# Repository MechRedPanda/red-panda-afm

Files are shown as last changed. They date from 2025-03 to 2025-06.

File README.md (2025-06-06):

# red-panda-afm
Build your own AFM for cheap!
## Background
This project aims to create a low-cost Atomic Force Microscope (AFM) using a 3D printer. The goal is to make AFM technology accessible and affordable for hobbyists and researchers.

## Features
- **Low Cost**: Utilizes 3D printing to reduce manufacturing costs.
- **DIY Friendly**: Designed for easy assembly and use.

## Requirements
- 3D Printer
- PCB and soldering
- OPU
- AFM probe

## Getting Started
Ready to build your own AFM? Check out our comprehensive [Building Instructions](BUILD_GUIDE.md) for step-by-step assembly guidance.

## License
This project is licensed under the MIT License.

## Contact
For any questions or support, please contact [your-email@example.com].

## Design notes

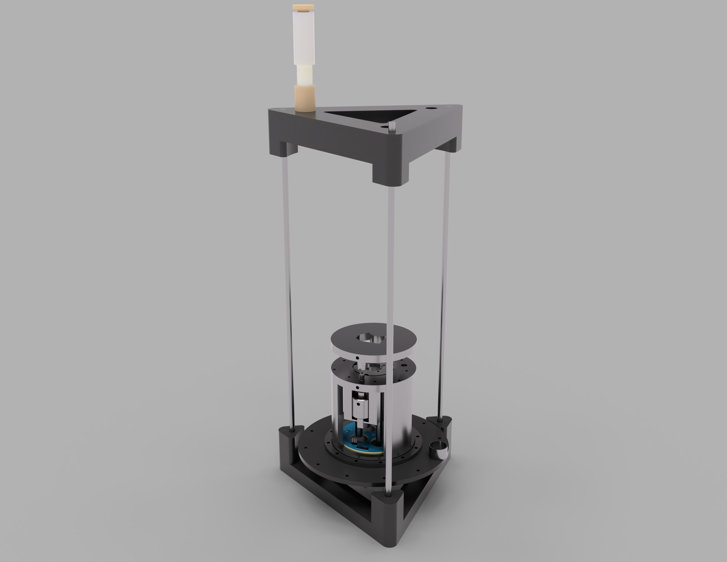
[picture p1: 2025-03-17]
cad/afm/ScanStage_2025-Mar-13_04-19-15AM-000_CustomizedView51960820746.png

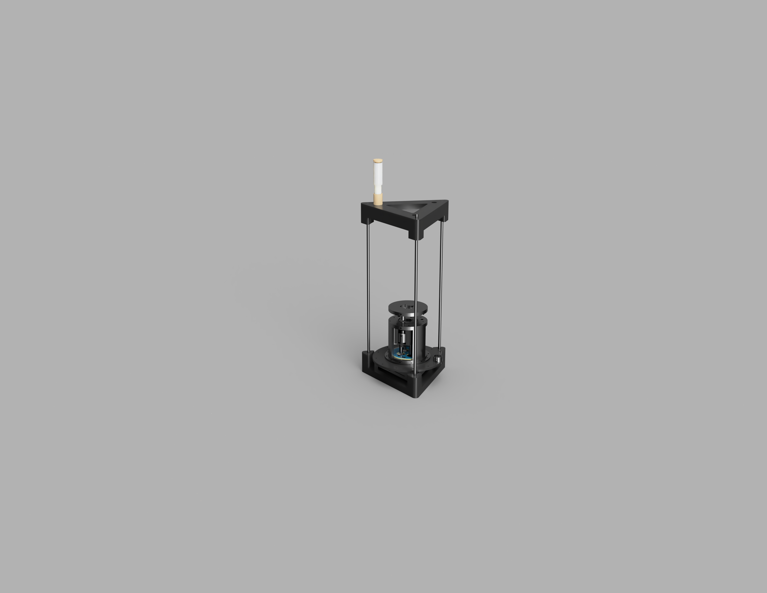
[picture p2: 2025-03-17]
cad/afm/ScanStage_2025-Mar-13_04-14-37AM-000_CustomizedView17416114158.png

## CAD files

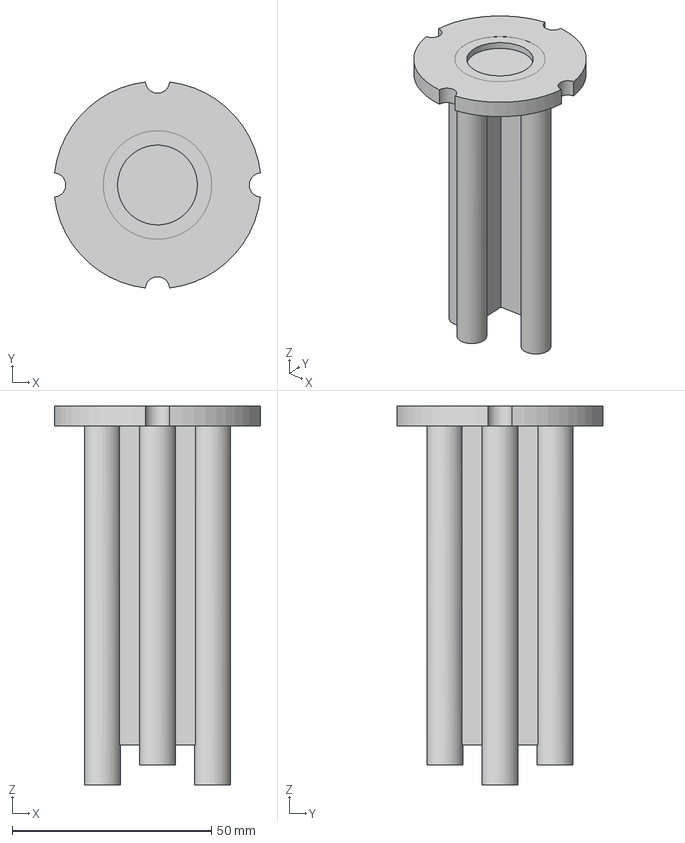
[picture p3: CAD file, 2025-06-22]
cad/afm/LongRagneScanner.step
51.7 x 51.7 x 95.0 mm

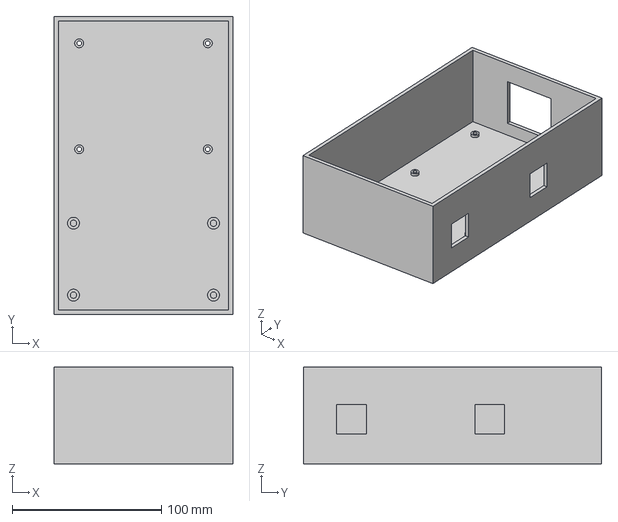
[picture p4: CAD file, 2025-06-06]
cad/afm/PCB_Box/PCB_Box_Lower.step
120.0 x 200.0 x 65.0 mm

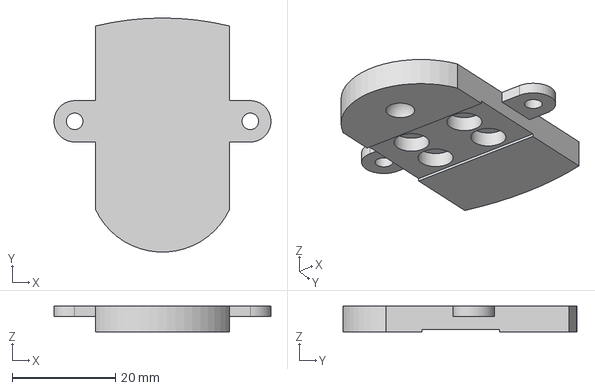
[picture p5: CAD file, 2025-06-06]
cad/afm/PCB_Box/ProbeHolderAdaptor.step
42.0 x 45.3 x 5.00 mm

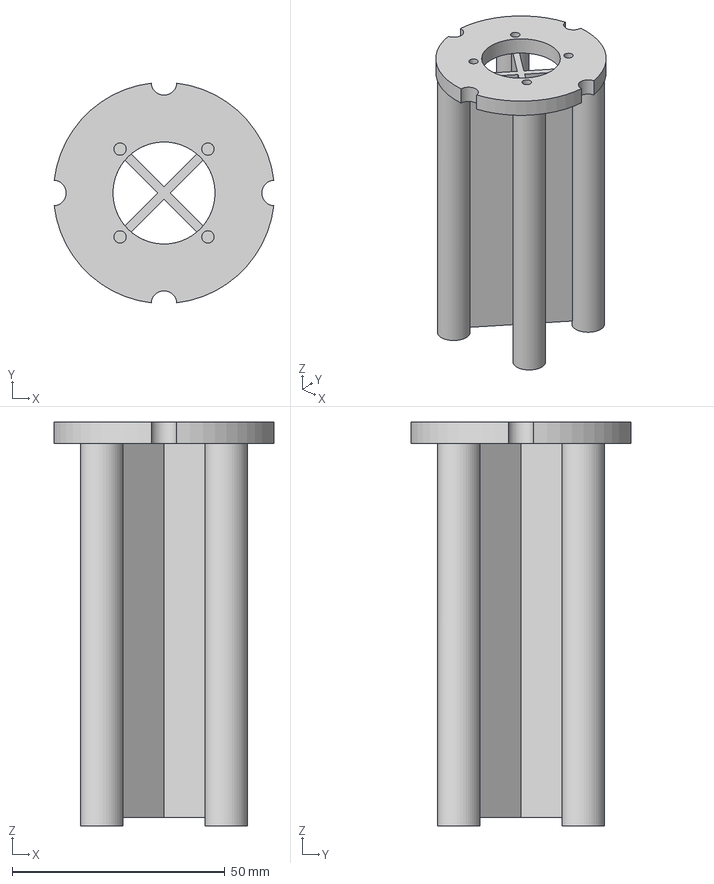
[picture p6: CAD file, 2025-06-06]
cad/afm/Scanner.step
51.7 x 51.7 x 95.0 mm

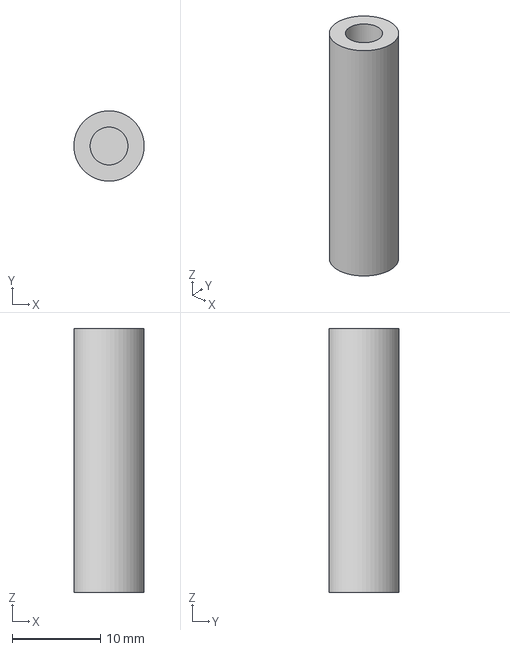
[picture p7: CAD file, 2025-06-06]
cad/afm/PCB_Box/Spacer.step
7.99 x 8.00 x 30.0 mm

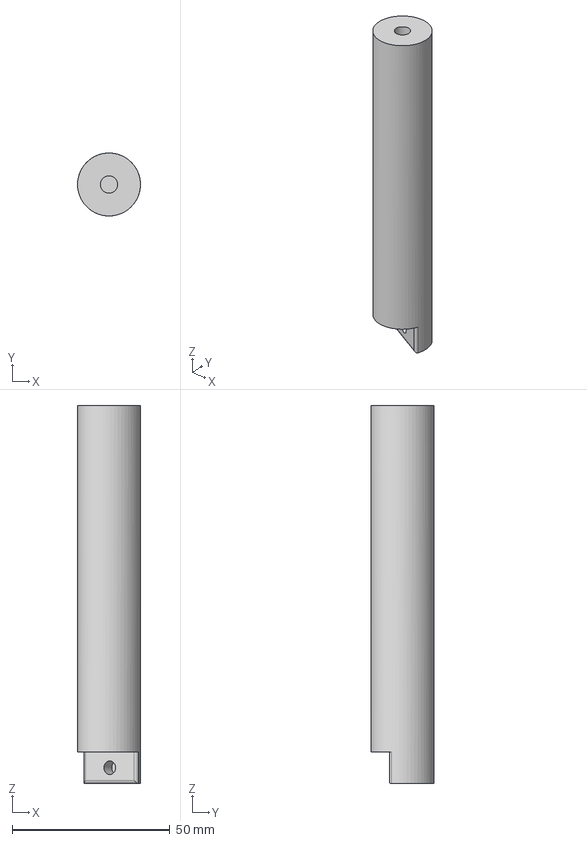
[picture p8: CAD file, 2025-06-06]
cad/afm/PlatformPillar.step
20.0 x 20.0 x 120.0 mm

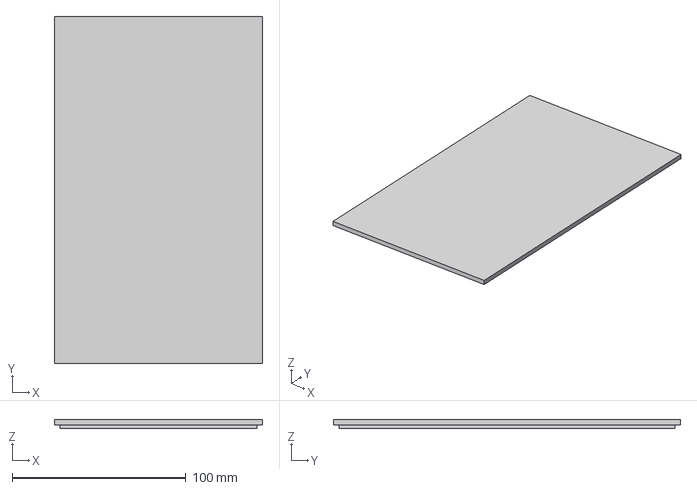
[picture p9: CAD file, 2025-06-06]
cad/afm/PCB_Box/PCB_Box_Cap.step
120.0 x 200.0 x 5.00 mm

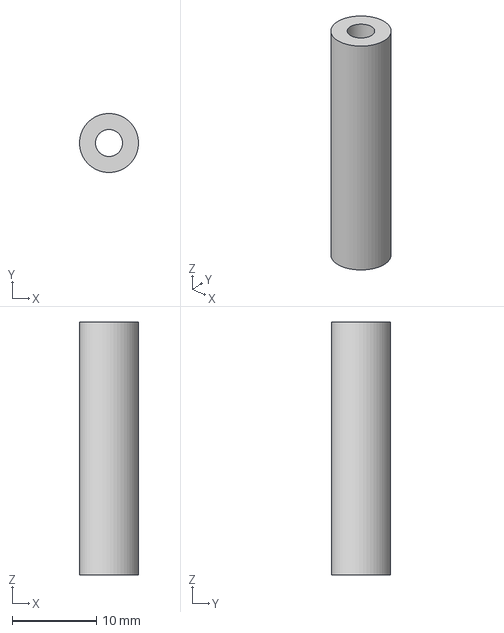
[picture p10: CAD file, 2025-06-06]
cad/afm/Spacer.step
6.99 x 7.00 x 30.0 mm

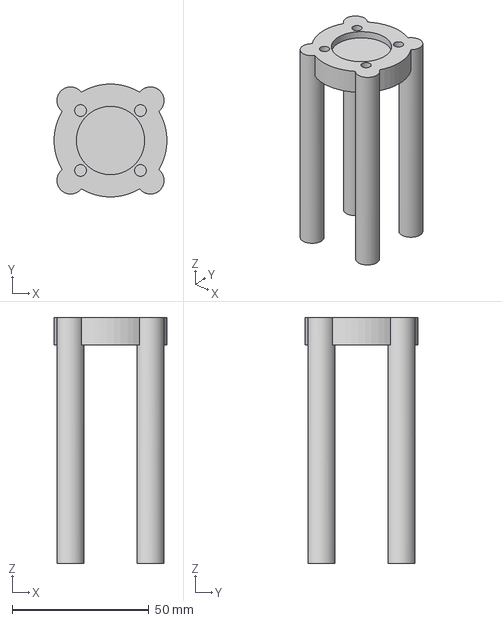
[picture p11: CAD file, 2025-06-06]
cad/afm/Sannerhead.step
41.2 x 41.2 x 90.0 mm

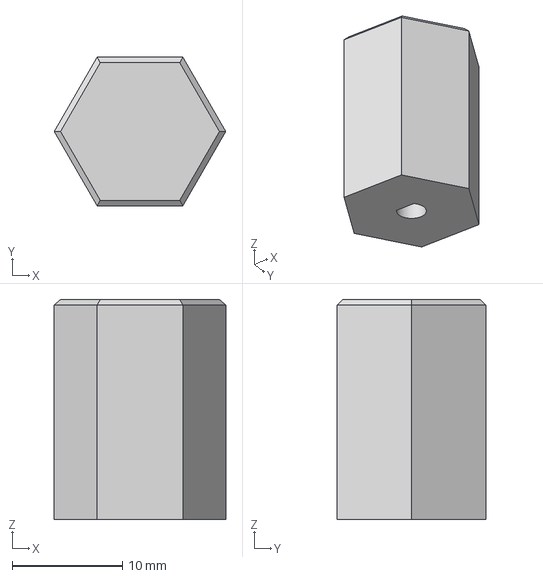
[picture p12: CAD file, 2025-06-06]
cad/afm/Shaft.step
15.6 x 13.5 x 20.0 mm

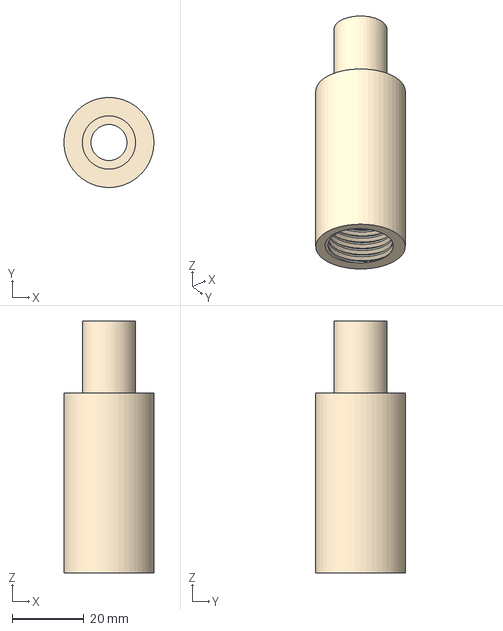
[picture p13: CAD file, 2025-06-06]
cad/afm/SpringHanger.step
25.0 x 25.0 x 70.0 mm

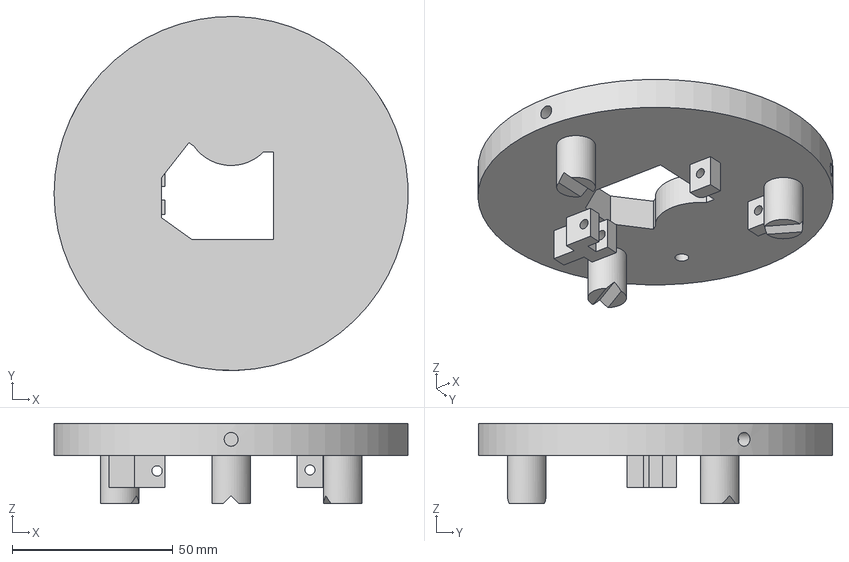
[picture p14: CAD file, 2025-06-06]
cad/afm/OPU_Plate.step
109.9 x 110.0 x 25.0 mm

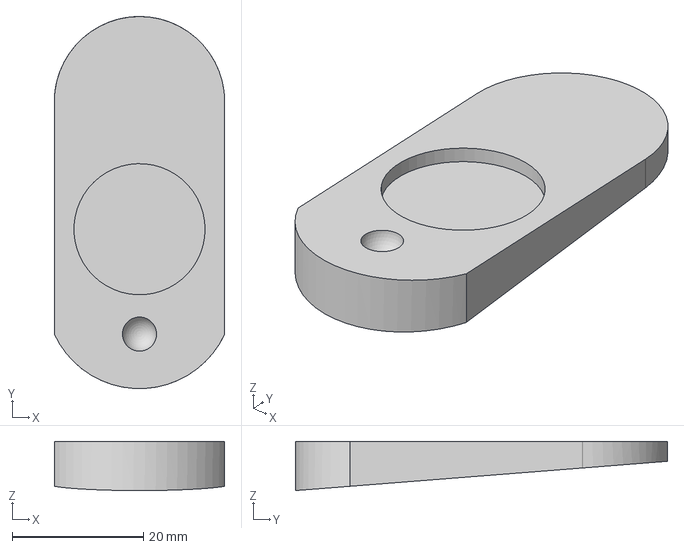
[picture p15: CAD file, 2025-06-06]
cad/afm/ProbeHolder.step
26.0 x 56.7 x 7.50 mm

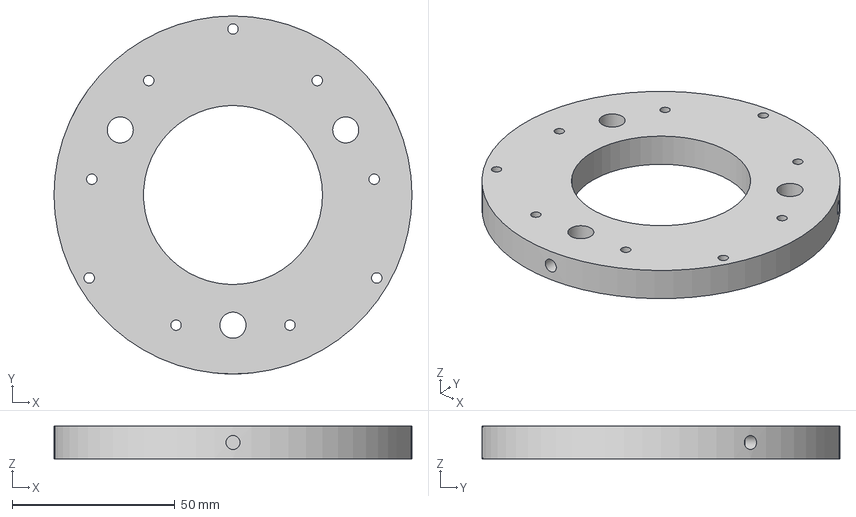
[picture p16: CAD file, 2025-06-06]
cad/afm/UpperFrame.step
110.0 x 110.0 x 10.0 mm

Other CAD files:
cad/afm/StepMotorUpperFrame.step
cad/afm/StepMotorUpperFrame2.step
cad/afm/KnobAdaptor.step
cad/afm/ProbeHolderAdaptor.step
cad/afm/AFM_Adaptor.step
cad/afm/LowerFrame.step
cad/afm/OPU_Tuning_Stand.step
cad/afm/PiezoAdaptor.step
cad/afm/Sannerhead.3mf
cad/afm/SpringExtension.step
cad/afm/StepMotorUpperFrame1.step

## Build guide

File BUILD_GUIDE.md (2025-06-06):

# DIY AFM Building Instructions

## Overview
This guide will walk you through building your own low-cost Atomic Force Microscope (AFM) using 3D printed components and readily available electronic parts.

## Required Materials

### 3D Printed Components
- Main frame structure
- Sample stage
- Cantilever mount
- Optical head assembly housing
- Z-axis adjustment mechanism

### Electronic Components
- **OPU (Optical Pick-Up Unit)**: DVD/Blu-ray laser assembly
- **AFM Probe/Cantilever**: Silicon nitride or silicon cantilever
- **Photodiode**: For detecting cantilever deflection
- **Piezoelectric actuators**: For fine positioning (X, Y, Z axes)
- **Arduino/microcontroller**: For control and data acquisition
- **Operational amplifiers**: For signal conditioning
- **Resistors and capacitors**: Various values for circuit construction

### Tools Required
- Soldering iron and solder
- Multimeter
- Small screwdrivers (Phillips and flathead)
- Wire strippers
- Hot glue gun (optional)
- Computer with USB port

## Assembly Steps

### Step 1: 3D Print Components
1. Download and print all STL files using PLA or PETG filament
2. Use 0.2mm layer height for best results
3. Support material may be required for some components
4. Post-process printed parts by removing supports and light sanding if needed

### Step 2: Prepare Electronics
1. **OPU Preparation**:
   - Carefully disassemble DVD/Blu-ray drive to extract OPU
   - Identify laser diode pins and photodiode connections
   - Test laser functionality with appropriate current limiting

2. **Control Circuit Assembly**:
   - Solder operational amplifier circuit for photodiode signal conditioning
   - Connect piezoelectric actuators to driver circuits
   - Wire Arduino/microcontroller to control interfaces

### Step 3: Mechanical Assembly
1. **Frame Assembly**:
   - Assemble main frame components
   - Install sample stage with smooth movement
   - Mount Z-axis adjustment mechanism

2. **Optical System Setup**:
   - Install OPU in optical head housing
   - Align laser beam path
   - Position photodiode for optimal signal detection

3. **Cantilever Mount**:
   - Install AFM probe/cantilever in mount
   - Ensure proper alignment with laser beam
   - Test mechanical stability

### Step 4: Electronics Integration
1. Connect all electronic components according to circuit diagram
2. Install control software on computer
3. Test all actuators and sensors
4. Calibrate photodiode response

### Step 5: Initial Testing
1. **System Check**:
   - Verify all connections
   - Test laser safety (never look directly into beam)
   - Check piezo actuator response

2. **Basic Functionality Test**:
   - Load test sample (e.g., calibration grating)
   - Attempt basic scanning operation
   - Verify data acquisition

## Safety Considerations

⚠️ **IMPORTANT SAFETY NOTES**:
- **Laser Safety**: Never look directly into the laser beam
- **Electrical Safety**: Ensure proper grounding and current limiting
- **Mechanical Safety**: Be careful with sharp AFM probes
- **Work in well-lit area** with proper ventilation when soldering

## Calibration

### Initial Calibration Steps
1. **Optical Alignment**:
   - Align laser spot on cantilever
   - Center photodiode signal
   - Optimize signal-to-noise ratio

2. **Mechanical Calibration**:
   - Calibrate piezo actuator sensitivity
   - Set appropriate feedback parameters
   - Test approach/retract functionality

## Troubleshooting

### Common Issues
- **No laser signal**: Check laser diode connections and current limiting
- **Poor image quality**: Verify cantilever alignment and cleanliness
- **Instability**: Check for vibrations and improve isolation
- **Electrical noise**: Improve shielding and grounding

### Performance Optimization
- Use vibration isolation table if available
- Shield electronics from electromagnetic interference
- Keep cables short and well-routed
- Regular maintenance of moving parts

## Software Setup
1. Install required drivers for microcontroller
2. Download AFM control software
3. Configure communication parameters
4. Test data acquisition and display

## Expected Performance
- **Lateral resolution**: ~100 nm (depending on probe quality)
- **Vertical resolution**: ~1 nm
- **Scan range**: Limited by piezo actuator range
- **Scan speed**: Variable, typically 0.1-10 Hz

## Next Steps
- Start with simple test samples (calibration gratings)
- Gradually move to more complex samples
- Consider upgrading components for better performance
- Join AFM community forums for tips and troubleshooting

## Support
For additional help and community support, refer to:
- Project repository issues section
- AFM hobbyist forums
- Local maker spaces with electronics expertise

---
**Note**: This is a complex project requiring patience and attention to detail. Take your time with each step and don't hesitate to ask for help when needed.

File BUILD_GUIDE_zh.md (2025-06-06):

# DIY AFM 制作说明

## 概述
本指南将指导您使用3D打印组件和现成的电子元件制作自己的低成本原子力显微镜（AFM）。

## 所需材料

### 3D打印组件
- 主框架结构
- 样品台
- 悬臂梁支架
- 光学头组件外壳
- Z轴调节机构

### 电子元件
- **OPU（光学拾取器）**: DVD/蓝光激光组件
- **AFM探针/悬臂梁**: 氮化硅或硅悬臂梁
- **光电二极管**: 用于检测悬臂梁偏转
- **压电驱动器**: 用于精密定位（X、Y、Z轴）
- **Arduino/微控制器**: 用于控制和数据采集
- **运算放大器**: 用于信号调理
- **电阻和电容**: 各种规格用于电路构建

### 所需工具
- 电烙铁和焊锡
- 万用表
- 小型螺丝刀（十字和一字）
- 剥线钳
- 热熔胶枪（可选）
- 带USB接口的计算机

## 组装步骤

### 步骤1: 3D打印组件
1. 下载并使用PLA或PETG耗材打印所有STL文件
2. 使用0.2mm层高以获得最佳效果
3. 某些组件可能需要支撑材料
4. 通过移除支撑和轻微打磨对打印件进行后处理

### 步骤2: 准备电子元件
1. **OPU准备**:
   - 小心拆解DVD/蓝光驱动器以提取OPU
   - 识别激光二极管引脚和光电二极管连接
   - 使用适当的限流测试激光功能

2. **控制电路组装**:
   - 焊接用于光电二极管信号调理的运算放大器电路
   - 连接压电驱动器到驱动电路
   - 将Arduino/微控制器连接到控制接口

### 步骤3: 机械组装
1. **框架组装**:
   - 组装主框架组件
   - 安装具有平滑运动的样品台
   - 安装Z轴调节机构

2. **光学系统设置**:
   - 将OPU安装在光学头外壳中
   - 对准激光束路径
   - 定位光电二极管以获得最佳信号检测

3. **悬臂梁支架**:
   - 在支架中安装AFM探针/悬臂梁
   - 确保与激光束的正确对准
   - 测试机械稳定性

### 步骤4: 电子集成
1. 根据电路图连接所有电子组件
2. 在计算机上安装控制软件
3. 测试所有驱动器和传感器
4. 校准光电二极管响应

### 步骤5: 初始测试
1. **系统检查**:
   - 验证所有连接
   - 测试激光安全（绝不直视光束）
   - 检查压电驱动器响应

2. **基本功能测试**:
   - 加载测试样品（如校准光栅）
   - 尝试基本扫描操作
   - 验证数据采集

## 安全注意事项

⚠️ **重要安全注意事项**:
- **激光安全**: 绝不直视激光束
- **电气安全**: 确保正确接地和限流
- **机械安全**: 小心尖锐的AFM探针
- **在照明良好的区域工作**，焊接时保持良好通风

## 校准

### 初始校准步骤
1. **光学对准**:
   - 将激光点对准悬臂梁
   - 居中光电二极管信号
   - 优化信噪比

2. **机械校准**:
   - 校准压电驱动器灵敏度
   - 设置适当的反馈参数
   - 测试接近/撤回功能

## 故障排除

### 常见问题
- **无激光信号**: 检查激光二极管连接和限流
- **图像质量差**: 验证悬臂梁对准和清洁度
- **不稳定**: 检查振动并改善隔离
- **电气噪声**: 改善屏蔽和接地

### 性能优化
- 如有条件，使用防振台
- 屏蔽电子元件免受电磁干扰
- 保持电缆短且布线良好
- 定期维护运动部件

## 软件设置
1. 为微控制器安装所需驱动程序
2. 下载AFM控制软件
3. 配置通信参数
4. 测试数据采集和显示

## 预期性能
- **横向分辨率**: ~100 nm（取决于探针质量）
- **纵向分辨率**: ~1 nm
- **扫描范围**: 受压电驱动器范围限制
- **扫描速度**: 可变，通常0.1-10 Hz

## 下一步
- 从简单的测试样品开始（校准光栅）
- 逐渐转向更复杂的样品
- 考虑升级组件以获得更好的性能
- 加入AFM社区论坛获取技巧和故障排除

## 支持
有关额外帮助和社区支持，请参考：
- 项目仓库问题部分
- AFM爱好者论坛
- 具有电子专业知识的本地创客空间

---
**注意**: 这是一个复杂的项目，需要耐心和对细节的关注。在每个步骤上花时间，需要帮助时不要犹豫。

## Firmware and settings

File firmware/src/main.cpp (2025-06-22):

#include "AD5761.hpp"
#include "ads8681.hpp"
#include <ArduinoJson.h>
#include <atomic>
#include <mutex>
#include "esp_task_wdt.h"
#include <cstring> // Needed for memcpy
#include <WiFi.h>  // Add WiFi library

// For thread synchronization
#include "freertos/FreeRTOS.h"
#include "freertos/semphr.h"
#include "freertos/portmacro.h"

// ============================================================================
// Configuration
// ============================================================================
#define DEBUG_ENABLED 0 // Set to 0 to disable all debug output

// Debug output macros - these will compile to nothing when debugging is disabled
#if DEBUG_ENABLED
#define DEBUG_PRINT(x) Serial.print(x)
#define DEBUG_PRINTLN(x) Serial.println(x)
#define DEBUG_PRINTF(format, ...) Serial.printf(format, __VA_ARGS__)
#else
#define DEBUG_PRINT(x)
#define DEBUG_PRINTLN(x)
#define DEBUG_PRINTF(format, ...)
#endif

// Forward declarations
void sendScanDataBuffer();

// ============================================================================
// PID Controller Class
// ============================================================================

class PIDController
{
public:
    PIDController(float kp = 1.0f, float ki = 0.0f, float kd = 0.0f,
                  float integralMin = -50000.0f, float integralMax = 50000.0f,
                  float slewRate = 100000.0f)
        : kp_(kp), ki_(ki), kd_(kd), integral_min_(integralMin),
          integral_max_(integralMax), slew_rate_(slewRate)
    {
        reset();
    }

    void setTunings(float kp, float ki, float kd)
    {
        kp_ = kp;
        ki_ = ki;
        kd_ = kd;
    }

    void setOutputLimits(float min, float max)
    {
        output_min_ = min;
        output_max_ = max;
    }

    void setIntegralLimits(float min, float max)
    {
        integral_min_ = min;
        integral_max_ = max;
    }

    void setSlewRate(float rate)
    {
        slew_rate_ = rate;
    }

    void reset()
    {
        integral_ = 0;
        last_error_ = 0;
        last_feedback_ = 0;
        last_output_ = 0;
        last_time_ = 0;  // Initialize to 0 to trigger first run protection
        filtered_d_term_ = 0;
    }

    float compute(float setpoint, float feedback)
    {
        uint64_t now = esp_timer_get_time();
        uint32_t dt = now - last_time_;
        
        // First run protection
        if (last_time_ == 0) {
            last_time_ = now;
            last_feedback_ = feedback;
            // Calculate initial output using proportional term only
            float error = setpoint - feedback;
            if (invert_)
                error = -error;
            last_output_ = kp_ * error + bias_;  // Initialize with proportional term plus bias
            return last_output_;
        }

        // Clamp minimum dt to 10us to prevent erratic integral updates
        if (dt < 100) dt = 100;

        float error = setpoint - feedback;
        if (invert_)
            error = -error;

        // Proportional term
        float p_term = kp_ * error;

        // Integral term with simple anti-windup (just clamping)
        integral_ += ki_ * error * dt / 1000000.0f;  // Convert microseconds to seconds
        integral_ = constrain(integral_, integral_min_, integral_max_);

        // Derivative term calculation (skip if Kd = 0)
        float d_term = 0.0f;
        if (kd_ != 0.0f) {
            float d_term_raw = -kd_ * (feedback - last_feedback_) / (dt / 1000000.0f);
            filtered_d_term_ = alpha_ * filtered_d_term_ + (1.0f - alpha_) * d_term_raw;
            d_term = filtered_d_term_;
        }

        // Calculate output with bias
        float pid_output = p_term + integral_ + d_term;
        float desired_output = pid_output + bias_;

        // Slew rate limiting
        float max_change = slew_rate_ * dt / 1000000.0f;
        float delta = desired_output - last_output_;
        if (abs(delta) > max_change)
        {
            delta = (delta > 0) ? max_change : -max_change;
        }
        float output = last_output_ + delta;

        // Output limiting
        output = constrain(output, output_min_, output_max_);

        // Update state
        last_error_ = error;
        last_feedback_ = feedback;
        last_output_ = output;
        last_time_ = now;

        return output;
    }

    void setInvert(bool invert) { invert_ = invert; }
    void setBias(float bias) { bias_ = bias; }
    void setAlpha(float alpha) { alpha_ = constrain(alpha, 0.0f, 1.0f); }

    // Getter methods
    float getKp() const { return kp_; }
    float getKi() const { return ki_; }
    float getKd() const { return kd_; }
    float getIntegral() const { return integral_; }
    float getBias() const { return bias_; }
    float getCurrentOutput() const { return last_output_; }
    bool getInvert() const { return invert_; }

private:
    // PID parameters
    float kp_, ki_, kd_;
    float integral_ = 0;
    float last_error_ = 0;
    float last_feedback_ = 0;
    float last_output_ = 0;
    uint64_t last_time_ = 0;  // Change from uint32_t to uint64_t for microsecond timing

    // Output limits
    float output_min_ = 0;
    float output_max_ = 65535;

    // Integral limits
    float integral_min_;
    float integral_max_;

    // Slew rate limit
    float slew_rate_;

    // Configuration
    bool invert_ = false;
    float bias_ = 0;

    // Derivative filtering
    float alpha_ = 0.2f; // Filter coefficient (0 < alpha < 1)
    float filtered_d_term_ = 0;
};



// ============================================================================
// Global Constants
// ============================================================================
static const int MAX_APPROACH_POINTS = 1000;
#define MAX_ADC_AVG_WINDOW_SIZE 16 // Maximum ADC average window size

#define DAC_Z_PROBE_TARGET 1000        // Fixed Z DAC value for probing (closer to 0)
#define DAC_Z_RETRACT_TARGET (1 << 15) // Fixed Z DAC value when retracted (mid-scale)
#define Z_CYCLE_STEPS 1000             // Fixed number of steps for Z probe/retract cycle
#define Z_STEP_DELAY_US 1              // Delay between Z DAC steps in approach cycle (us)

// Scan Data Point Structure
struct ScanDataPoint {
    uint16_t i;          // X index in the scan grid
    uint16_t j;          // Y index in the scan grid
    uint16_t adc_0;      // ADC reading
    uint16_t dac_z;      // Current Z DAC value
    bool is_trace;       // true for trace, false for retrace
};

// Scan Buffer Constants
const int SCAN_BUFFER_SIZE = 256;
ScanDataPoint scan_buffer[SCAN_BUFFER_SIZE];  // Remove extern keyword

// ============================================================================
// Hardware Configuration
// ============================================================================

// Pin Definitions
#define DIR_PIN 27
#define STEP_PIN1 25
#define STEP_PIN2 33
#define STEP_PIN3 32
#define SLEEP_PIN 26

// SPI Pin Definitions
#define VSPI_SCK 18
#define VSPI_MISO 19
#define VSPI_MOSI 23
#define HSPI_SCK 14
#define HSPI_MISO 12
#define HSPI_MOSI 13

// SPI Interface Instances
SPIClass opu_spi = SPIClass(VSPI);
SPIClass driver_spi = SPIClass(HSPI);

// ============================================================================
// Device Instances
// ============================================================================

// DAC Instances
AD5761 dac_f = AD5761(&opu_spi, 16, 0b0000000101101);
AD5761 dac_t = AD5761(&opu_spi, 17, 0b0000000101101);
AD5761 dac_x = AD5761(&driver_spi, 15, 0b0000000101000);
AD5761 dac_y = AD5761(&driver_spi, 2, 0b0000000101000);
AD5761 dac_z = AD5761(&driver_spi, 4, 0b0000000101000);

// ADC Instances
ADC_ads8681 adc_0 = ADC_ads8681(&opu_spi, 21, 0x0004);
ADC_ads8681 adc_1 = ADC_ads8681(&opu_spi, 5, 0x0003);

// ============================================================================
// State Definitions
// ============================================================================

// System States
enum class SystemState
{
    IDLE = 0,
    FOCUSING = 1,
    APPROACHING = 2,
    SCANNING = 3
};

// Motor States
enum class MotorStatus
{
    IDLE = 0,
    MOVING = 1,
    ERROR = 2
};

// Approach Phase States (for Woodpecker)
enum class ApproachPhase
{
    IDLE = 0,
    READY_TO_STEP = 1,
    STEPPING_MOTOR = 2,
    READY_TO_PROBE = 3,
    Z_PROBING = 4,
    Z_RETRACTING = 5,
    INTERACTION_FOUND = 6,
    FINISHED_MAX_STEPS = 7
};

// Motor State Structure
struct MotorState
{
    int32_t current_position = 0;
    int32_t target_position = 0;
    uint32_t last_update = 0;
    MotorStatus status = MotorStatus::IDLE;
    uint8_t active = 0; // 0 = inactive, 1-3 = motor number
};

// AFM System State Structure
struct AFMState
{
    // DAC/ADC Values - Default DAC values set to mid-scale (0V)
    uint16_t dac_f_val = (1 << 15);
    uint16_t dac_t_val = (1 << 15);
    uint16_t dac_x_val = (1 << 15);
    uint16_t dac_y_val = (1 << 15);
    uint16_t dac_z_val = (1 << 15);
    uint16_t adc_0_val = 0;
    uint16_t adc_1_val = 0;
    uint16_t max_dac_y_step = 1;  // Add this line for Y DAC step limiting

    // ADC Moving Average
    float adc_0_avg = 0.0f;
    float adc_1_avg = 0.0f;
    uint16_t adc_0_history[MAX_ADC_AVG_WINDOW_SIZE];
    uint16_t adc_1_history[MAX_ADC_AVG_WINDOW_SIZE];
    uint8_t adc_history_index = 0;
    uint8_t adc_history_count = 0;
    uint8_t adc_avg_window_size = 3;

    // Motor States
    MotorState motors[3];

    // System State
    int32_t timestamp = 0;
    SystemState current_state = SystemState::IDLE;

    // PID Control
    bool pid_enabled = false;
    float pid_target = 0.0f;
    PIDController pid_controller;

    // Approach Data
    struct ApproachData
    {
        int32_t steps;
        float adc;
        int32_t position;
    };
    ApproachData approach_data[MAX_APPROACH_POINTS];
    int approach_data_count = 0;
    bool approach_running = false;
    uint8_t approach_motor = 0;
    int approach_step_size = 0;
    int approach_direction = 0;
    uint16_t approach_threshold = 0;
    float approach_initial_adc = 0.0f;
    uint16_t approach_initial_dac_z = 0;  // Add this field to store initial DAC Z value
    int32_t approach_initial_position = 0;
    int32_t approach_max_steps = 0;
    unsigned long approach_polling_interval = 50;
    unsigned long approach_last_update = 0;
    int32_t approach_last_stored_step = 0;
    unsigned int approach_step_delay = 500;
    int32_t approach_total_steps_taken = 0;

    // Scan Data & State
    uint16_t scan_buffer_head = 0;
    uint16_t scan_buffer_tail = 0;
    uint16_t scan_buffer_count = 0;
    bool scan_active = false;
    uint16_t scan_x_start = 0;
    uint16_t scan_x_end = 0;
    uint16_t scan_y_start = 0;
    uint16_t scan_y_end = 0;
    uint16_t scan_resolution = 256;  // Unified resolution for both X and Y
    uint16_t scan_current_x_index = 0;
    uint16_t scan_current_x = 0;
    bool scan_y_forward = true;
    // Add line start wait configuration
    uint32_t scan_line_start_wait_ms = 100; // Default 10ms wait at start of each line
    uint64_t scan_line_start_wait_until_us = 0; // When to end the current wait
    bool scan_line_waiting = false; // Whether currently waiting at start of line

    // Y-axis step size control
    uint16_t scan_y_micro_steps = 1;  // Number of micro-steps between data collection points
    uint16_t scan_y_current_step = 0; // Current step count within a micro-step sequence
    uint16_t scan_y_total_steps = 0;  // Total steps in Y direction (resolution * micro_steps)
    uint16_t scan_y_current_micro_step = 0; // Current micro-step index
    uint32_t scan_y_micro_step_wait_us = 0; // Wait time between micro-steps in microseconds
    uint64_t scan_y_next_micro_step_time_us = 0; // When to perform the next micro-step

    // Continuous Scan State
    bool scan_continuous_y = false;
    float scan_y_velocity = 0.0f;
    uint16_t scan_y_current_dac = 0;
    uint64_t scan_y_ramp_start_time_us = 0;
    uint64_t scan_next_point_time_us = 0;
    uint64_t scan_point_interval_us = 0;
    int32_t scan_y_steps_taken = 0;
    int32_t scan_points_per_line = 0;
    float scan_line_frequency_hz = 0.0f;

    // Control Loop Timing
    uint32_t control_loop_last_period_us = 0;
    uint64_t control_loop_total_period_us = 0;
    uint32_t control_loop_count = 0;
    uint64_t last_control_time_us = 0;  // Add this field

    // DAC XY Ramping State
    bool ramp_active = false;
    uint16_t ramp_target_x = 0;
    uint16_t ramp_target_y = 0;
    uint16_t ramp_target_z = 0;
    uint16_t ramp_start_x = 0;
    uint16_t ramp_start_y = 0;
    uint16_t ramp_start_z = 0;
    int32_t ramp_delta_x = 0;
    int32_t ramp_delta_y = 0;
    int32_t ramp_delta_z = 0;
    int ramp_duration_ms = 1000;
    int ramp_step_delay_ms = 1;
    int ramp_total_steps = 0;
    int ramp_current_step = 0;
    uint64_t ramp_next_step_time_us = 0;

    // Scan Data Collection Flag
    bool scan_data_collected = false;
};

// ============================================================================
// Global Variables
// ============================================================================

AFMState current_afm_state;
std::atomic<bool> adc_busy(false);
std::atomic<bool> scan_data_ready_to_send; // Flag for push mechanism (initialized in setup)
const int SCAN_SEND_CHUNK_SIZE = 32;       // Number of points to send per loop iteration

// Add mutex for scan buffer protection
SemaphoreHandle_t scan_buffer_mutex = NULL;

// Motor Control State
struct MotorControlState
{
    uint8_t active_motor;
    int remaining_steps;
    int direction;
    unsigned long next_step_time;
    unsigned int step_delay;
    bool is_moving;
};

MotorControlState motor_ctrl_state = {0, 0, 0, 0, 500, false};

// ============================================================================
// Hardware Initialization
// ============================================================================

void setupMotorPins()
{
    pinMode(DIR_PIN, OUTPUT);
    pinMode(STEP_PIN1, OUTPUT);
    pinMode(STEP_PIN2, OUTPUT);
    pinMode(STEP_PIN3, OUTPUT);
    pinMode(SLEEP_PIN, OUTPUT);
    digitalWrite(SLEEP_PIN, LOW); // Start with drivers in sleep mode
}

void setupSPI()
{
    opu_spi.begin(VSPI_SCK, VSPI_MISO, VSPI_MOSI, -1);
    driver_spi.begin(HSPI_SCK, HSPI_MISO, HSPI_MOSI, -1);
}

// ============================================================================
// Device Control Functions
// ============================================================================

void resetXYDacRange(uint16_t new_mode)
{
    // Update the mode/range of X and Y DACs
    dac_x.setMode(new_mode);
    dac_y.setMode(new_mode);
    
    // Reset DACs to apply the new mode
    dac_x.reset();
    dac_x.write(1 << 15); // Set to 0V
    dac_y.reset();
    dac_y.write(1 << 15); // Set to 0V
    
    // Update state
    current_afm_state.dac_x_val = 1 << 15;
    current_afm_state.dac_y_val = 1 << 15;
}

void resetAllDevices()
{
    // Reset and initialize DACs
    dac_f.reset();
    dac_f.write(1 << 15); // Set to 0V
    dac_t.reset();
    dac_t.write(1 << 15);
    dac_x.reset();
    dac_x.write(1 << 15);
    dac_y.reset();
    dac_y.write(1 << 15);
    dac_z.reset();
    dac_z.write(1 << 15);

    // Reset ADCs
    adc_0.reset();
    adc_1.reset();

    // Update state
    current_afm_state.dac_f_val = 1 << 15;
    current_afm_state.dac_t_val = 1 << 15;
    current_afm_state.dac_x_val = 1 << 15;
    current_afm_state.dac_y_val = 1 << 15;
    current_afm_state.dac_z_val = 1 << 15;
    current_afm_state.current_state = SystemState::IDLE;
}

void restoreDeviceStates()
{
    dac_f.reset();
    dac_f.write(current_afm_state.dac_f_val);
    dac_t.reset();
    dac_t.write(current_afm_state.dac_t_val);
    dac_x.reset();
    dac_x.write(current_afm_state.dac_x_val);
    dac_y.reset();
    dac_y.write(current_afm_state.dac_y_val);
    dac_z.reset();
    dac_z.write(current_afm_state.dac_z_val);
    adc_0.reset();
    adc_1.reset();
}

// ============================================================================
// Motor Control Functions
// ============================================================================

bool startMotorMovement(uint8_t motor_number, int steps, int direction, unsigned int step_delay = 500)
{
    if (motor_number < 1 || motor_number > 3)
        return false;
    if (steps <= 0 || motor_ctrl_state.is_moving ||
        current_afm_state.motors[motor_number - 1].status == MotorStatus::MOVING)
    {
        return false;
    }

    // Update AFM state
    current_afm_state.motors[motor_number - 1].target_position =
        current_afm_state.motors[motor_number - 1].current_position +
        (direction ? steps : -steps);
    current_afm_state.motors[motor_number - 1].status = MotorStatus::MOVING;
    current_afm_state.motors[motor_number - 1].last_update = millis();
    current_afm_state.motors[motor_number - 1].active = motor_number;

    // Hardware control
    digitalWrite(SLEEP_PIN, HIGH);
    delay(1); // Wake-up time
    digitalWrite(DIR_PIN, direction);
    delayMicroseconds(50);

    // Update control state
    motor_ctrl_state.active_motor = motor_number;
    motor_ctrl_state.remaining_steps = steps;
    motor_ctrl_state.direction = direction;
    motor_ctrl_state.step_delay = step_delay;
    motor_ctrl_state.next_step_time = micros() + step_delay;
    motor_ctrl_state.is_moving = true;

    return true;
}

void updateMotorMovement()
{
    if (!motor_ctrl_state.is_moving)
        return;

    unsigned long current_time = micros();
    if (current_time >= motor_ctrl_state.next_step_time)
    {
        // Calculate steps to take
        unsigned long time_since_last_step = current_time - motor_ctrl_state.next_step_time;
        int steps_to_take = 1 + (time_since_last_step / motor_ctrl_state.step_delay);
        steps_to_take = min(steps_to_take, motor_ctrl_state.remaining_steps);

        // Get step pin
        uint8_t step_pin;
        switch (motor_ctrl_state.active_motor)
        {
        case 1:
            step_pin = STEP_PIN1;
            break;
        case 2:
            step_pin = STEP_PIN2;
            break;
        case 3:
            step_pin = STEP_PIN3;
            break;
        default:
            return;
        }

        // Pulse step pin
        for (int i = 0; i < steps_to_take; i++)
        {
            digitalWrite(step_pin, HIGH);
            delayMicroseconds(10);
            digitalWrite(step_pin, LOW);
            delayMicroseconds(10);
        }

        // Update control state
        motor_ctrl_state.remaining_steps -= steps_to_take;
        motor_ctrl_state.next_step_time = current_time + motor_ctrl_state.step_delay;

        // Update AFM state
        uint8_t motor_idx = motor_ctrl_state.active_motor - 1;
        current_afm_state.motors[motor_idx].current_position +=
            (motor_ctrl_state.direction ? steps_to_take : -steps_to_take);
        current_afm_state.motors[motor_idx].last_update = millis();

        // Check completion
        if (motor_ctrl_state.remaining_steps <= 0)
        {
            motor_ctrl_state.is_moving = false;
            current_afm_state.motors[motor_idx].status = MotorStatus::IDLE;
            digitalWrite(SLEEP_PIN, LOW);
        }
    }
}

bool isMotorMoving()
{
    if (motor_ctrl_state.is_moving)
        return true;
    for (int i = 0; i < 3; i++)
    {
        if (current_afm_state.motors[i].status == MotorStatus::MOVING)
            return true;
    }
    return false;
}

bool stopMotor()
{
    if (!motor_ctrl_state.is_moving)
        return false;

    uint8_t motor_idx = motor_ctrl_state.active_motor - 1;
    current_afm_state.motors[motor_idx].status = MotorStatus::IDLE;
    current_afm_state.motors[motor_idx].last_update = millis();

    motor_ctrl_state.is_moving = false;
    motor_ctrl_state.active_motor = 0;
    digitalWrite(SLEEP_PIN, LOW);

    return true;
}

bool moveMotorBlocking(uint8_t motor_number, int steps, int direction, unsigned int step_delay = 500)
{
    if (!startMotorMovement(motor_number, steps, direction, step_delay))
        return false;
    while (motor_ctrl_state.is_moving)
        updateMotorMovement();
    return true;
}

// ============================================================================
// ADC Control Functions
// ============================================================================

bool adcInUse()
{
    return adc_busy.load();
}

bool acquireADC()
{
    bool expected = false;
    return adc_busy.compare_exchange_strong(expected, true);
}

void releaseADC()
{
    adc_busy = false;
}
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
void loop()
{
    // Check if scan data needs to be sent (push mechanism)
    if (scan_data_ready_to_send.load())
    {
        sendScanDataBuffer(); // Send buffered data and reset flag
    }

    // Check for incoming commands
    if (Serial.available())
    {
        String json_command = Serial.readStringUntil('\n');
        json_command.trim();

        if (json_command.length() > 0)
        {
            String response_string = processCommand(json_command);
            // processCommand now never returns "" for scan data,
            // as CSV data is sent via sendScanDataBuffer.
            // So, always print the JSON response from processCommand.
            Serial.println(response_string);
        }
    }
}

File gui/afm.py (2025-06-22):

from enum import Enum
import json
import threading
from collections import deque
from datetime import datetime
import time
import serial
from serial.tools import list_ports
from typing import Dict, Optional, Union, List, Tuple, Any
from dataclasses import dataclass, field
import numpy as np
import queue # Added for response queue
import tifffile
import os

# Default serial port settings
DEFAULT_PORT = None  # Will auto-detect if None
BAUDRATE = 115200
TIMEOUT = 1
QUEUE_MAXLEN = 10000
SERIAL_READ_TIMEOUT = 0.1 # Timeout for serial read attempts in background thread
RESPONSE_TIMEOUT = 2.0 # Default timeout for waiting for a command response
SCAN_SEND_CHUNK_SIZE = 32 # Matches firmware setting for max points per binary chunk


class AFMState(Enum):
    """Enum representing the possible states of the AFM system."""
    IDLE = "IDLE"
    FOCUSING = "FOCUSING"
    APPROACHING = "APPROACHING"
    SCANNING = "SCANNING"


@dataclass
class MotorStatus:
    """Data class representing the status of a motor."""
    position: int = 0       # Current step position
    target: int = 0         # Target position
    is_running: bool = False  # True if motor is currently moving


@dataclass
class AFMStatus:
    """Data class representing the complete status of the AFM system."""
    # --- Fields without defaults --- MUST come first
    timestamp: int          # Timestamp in milliseconds
    adc_0: int              # ADC channel 0 reading (raw)
    adc_1: int              # ADC channel 1 reading (raw)
    adc_0_avg: float        # ADC channel 0 reading (averaged)
    adc_1_avg: float        # ADC channel 1 reading (averaged)
    dac_f: int              # Feedback DAC value
    dac_t: int              # Tuning DAC value
    dac_x: int              # X-axis DAC value
    dac_y: int              # Y-axis DAC value
    dac_z: int              # Z-axis DAC value
    loop_last_period_us: int = 0 # Firmware provides this

    # --- Fields with defaults --- MUST come after non-defaults
    motor_1: MotorStatus = field(default_factory=MotorStatus)  # Motor 1 status
    motor_2: MotorStatus = field(default_factory=MotorStatus)  # Motor 2 status
    motor_3: MotorStatus = field(default_factory=MotorStatus)  # Motor 3 status
    state: AFMState = AFMState.IDLE
    loop_last_freq_hz: float = 0.0 # Firmware provides this
    loop_avg_freq_hz: float = 0.0  # Firmware provides this


class AFM:
    """Main class for controlling the Atomic Force Microscope system."""

    def __init__(self):
        """Initialize the AFM system with default settings."""
        self.serial_port = DEFAULT_PORT
        self.baudrate = BAUDRATE
        self.timeout = TIMEOUT
        self.serial_ports = []
        self.serial_conn = None
        self.status_queue = deque(maxlen=QUEUE_MAXLEN)
        self.busy = False
        self.busy_lock = threading.Lock()  # Add lock for busy flag
        self.focus_interrupted = False
        self.current_state = AFMState.IDLE
        self.focus_results = []
        self.focus_running = False
        self.motor_delay = 500  # us, default motor delay
        self._approach_params = None
        self._approach_thread = None
        self.approach_data = []  # Store approach data points
        self.optimal_focus_value = None  # Store the optimal focus value
        self.serial_lock = threading.Lock()
        self.response_queue = queue.Queue()
        self._read_thread = None
        self._stop_read_thread = threading.Event()
        
        # Modified for separate trace/retrace storage
        self.scan_data_trace = deque()  # Store trace (first pass) scan data
        self.scan_data_retrace = deque()  # Store retrace (second pass) scan data
        self.scan_data = deque()  # Maintain original for backward compatibility
        
        self.scan_running = False
        self._scan_event = threading.Event()  # Added for potential future use
        self.scan_resolution = 0  # Store resolution of the current/last scan
        
        # Initialize scan boundary attributes
        self.scan_x_start = 0
        self.scan_x_end = 0
        self.scan_y_start = 0
        self.scan_y_end = 0
        
        # Add new Y-axis control attributes
        self.scan_y_micro_steps = 1  # Number of micro-steps between data collection points
        self.scan_y_micro_step_wait_us = 0  # Wait time between micro-steps in microseconds

    # Serial Communication Methods
    def get_serial_ports(self) -> List[Any]:
        """Get a list of available serial ports."""
        self.serial_ports = list_ports.comports()
        return self.serial_ports

    def find_afm_device(self) -> Optional[str]:
        """Try to automatically find the AFM device by checking serial ports."""
        ports = list_ports.comports()
        for port in ports:
            if "USB" in port.description or "Serial" in port.description:
                return port.device
        return None

    def connect(self, port: Optional[str] = None, baudrate: int = BAUDRATE,
                timeout: float = TIMEOUT) -> bool:
        """Connect to the AFM device via serial."""
        try:
            self.baudrate = baudrate
            self.timeout = timeout

            if port is None:
                print("Could not auto-detect AFM device. Please specify port manually.")
                return False

            self.serial_port = port
            self.serial_conn = serial.Serial(
                port=self.serial_port,
                baudrate=self.baudrate,
                timeout=self.timeout
            )

            self.serial_conn.reset_input_buffer()
            self.serial_conn.reset_output_buffer()

            # Start the background reader thread
            self._stop_read_thread.clear()
            self._read_thread = threading.Thread(target=self._serial_read_loop, daemon=True)
            self._read_thread.start()

            print(f"Connected to {self.serial_port} at {self.baudrate} baud")
            return True
        except Exception as e:
            print(f"Error connecting: {e}")
            self.serial_conn = None
            return False

    def is_connected(self) -> bool:
        """Check if the AFM is connected."""
        return self.serial_conn is not None and self.serial_conn.is_open

    def close(self) -> None:
        """Close the serial connection and stop the reader thread."""
        if self._read_thread and self._read_thread.is_alive():
            print("Stopping reader thread...")
            self._stop_read_thread.set()
            self._read_thread.join(timeout=2.0) # Wait for thread to finish
            if self._read_thread.is_alive():
                print("Warning: Reader thread did not stop gracefully.")
            self._read_thread = None
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

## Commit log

2025-02-02 add function to control dac/adc
    [OPU_Holder.step, ProbeHolder.step, opu_test v10.step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]
2025-03-17 add step motor control
    [KnobAdaptor.step, LowerFrame.step, OPU_Plate.step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]
2025-03-17 fix adc bug
2025-04-06 bck for wifi
    [ProbeHolder.step, ProbeHolderAdaptor.step]
2025-04-06 add motor control back
    [ProbeHolder.step, ProbeHolderAdaptor.f3d, ProbeHolderAdaptor.step]
2025-04-06 add AFM_Adaptor STEP file and update GUI
    [AFM_Adaptor.step]
2025-04-14 add gui for focus and approachx
    [AFM_Adaptor.step, OPU_Tuning_Stand.step, PlatformPillar.step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]
2025-04-14 add pid control
2025-04-14 tune pid calculation methods
2025-04-19 add scan function with ring buffer so i no longer have points missed.
    [afm.py, afm_gui.py, main.cpp]
2025-04-24 add avg to adc tune gui
2025-04-26 change adc driver
    [Scanner.step]
2025-04-26 refactor pid
2025-04-29 fix pid bug
2025-05-22 bug fix
    [LongRagneScanner.step, LowerFrame.step, PiezoAdaptor.step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]
2025-05-22 add AFM v1.f3z
    [OPU_Holder.step, ProbeHolder.step, ProbeHolderAdaptor.step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]
2025-06-06 add build guide and readme
    [AFM_Adaptor.step, KnobAdaptor.step, LongRagneScanner.step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]
2025-06-22 update gui code
    [LongRagneScanner.step]
